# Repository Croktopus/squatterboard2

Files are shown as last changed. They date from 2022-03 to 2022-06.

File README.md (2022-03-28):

# squatterboard2

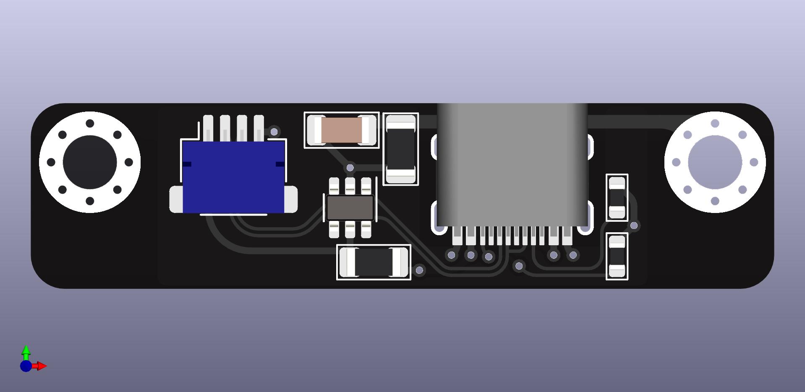
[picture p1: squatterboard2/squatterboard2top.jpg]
thumb


This is an update to the [squatterboard project](https://github.com/Croktopus/squatterboard), meant to resolve issues I have with the original. If you're not familiar with the original, the reason I made this was to make a daughterboard with a "squatter" profile than the standard set by the [Unified Daughterboard](https://github.com/ai03-2725/Unified-Daughterboard) (UDB), since I almost never have room in my cases for a daughterboard with those dimensions.

Electrically, it is compatible with the UDB's pinout, so it can work with any PCB compatible with the UDB. I honestly do not know how it compares for effectiveness because I don't have access to proper testing equipment, and I do know that the routing is not perfectly optimal (I made a couple slight compromises to fit everything a bit tighter and, I'll be honest, to keep the routing clean), but I'm confident that it is good enough (Cunningham's Law inc).

While you are welcome to use this DB as is without any modification, I am not proposing it as an alternative standard, and I encourage you to modify it to fit your needs, because that's why it was made in the first place; as a modification of the UDB concept to fit my needs.

Major changes from the original squatterboard:

* Built from scratch in KiCad 6
* Simplified the schematic & componentry
* Made it a bit squatter (loses physical compatibility, but I kinda just don't care about that, as I said above you can modify it to fit your needs, including moving some stuff around to restore physical compat)
* Reorganized libraries, added license, basically just trying to make the whole package a bit more portable so you don't get hit with errors when you download it and try to play around with it - let me know if I failed on that front, this was one of the big reasons I had for redoing this whole thing

Major changes relative to the UDB

* Size and shape (obviously)
* Optimized for JLC assembly with basic parts wherever possible (production files are included, though they haven't been tested as of writing)
* 2 M3 screws instead of 4 M2

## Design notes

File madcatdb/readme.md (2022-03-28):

this directory is for a modification I've made to the squatterboard for a specific keyboard I'm working on where it will be mounted upside down, so the mounting hole not used for shielding is flipped. This change is almost entirely aesthetic, feel free to ignore this directory entirely.

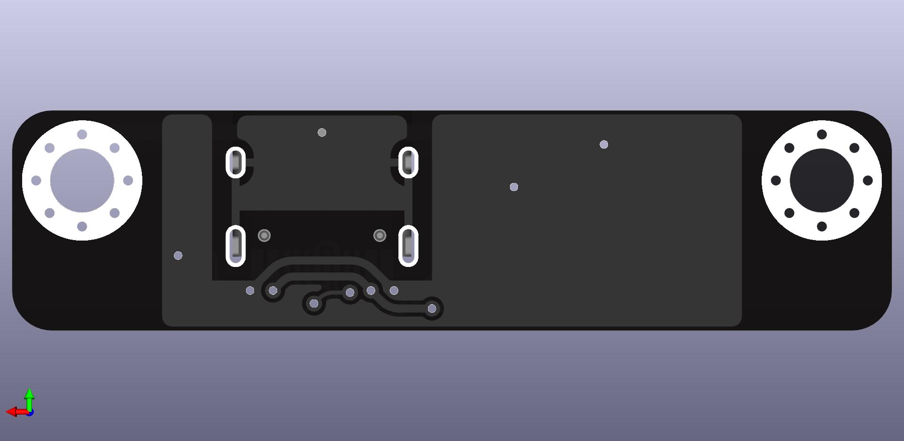
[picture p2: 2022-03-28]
madcatdb/madcatdbbot.jpg

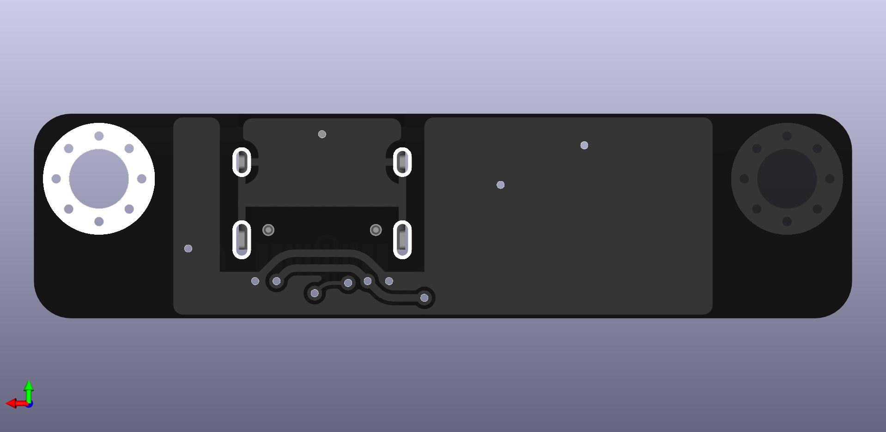
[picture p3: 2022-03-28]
squatterboard2/squatterboard2bot.jpg

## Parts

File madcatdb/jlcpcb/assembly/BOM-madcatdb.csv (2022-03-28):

Comment | Designator | Footprint | LCSC
Conn_01x04 | J2 | JST_SH_SM04B-SRSS-TB-Handsoldering | C160404
USB_C_Receptacle_USB2.0 | J1 | USB_C_Receptacle_HRO_TYPE-C-31-M-12 | C167321
1M | R3 | R_1206_3216Metric | C17927
5.1k | R1,R2 | R_0603_1608Metric | C23186
100n | C1 | C_1206_3216Metric | C24497
500mA | F1 | Fuse_1206_3216Metric | C70076
SRV05-4 | U1 | SOT-23-6 | C85364
M3 | H1 | M3_Via_Hole_NC
M3_Pad | H2 | M3_Via_Hole
JLCJLCJLCJLC | H3 | JLCJLCJLCJLC

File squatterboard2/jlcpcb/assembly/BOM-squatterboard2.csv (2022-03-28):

Comment | Designator | Footprint | LCSC
1M | R3 | R_1206_3216Metric
USB_C_Receptacle_USB2.0 | J1 | USB_C_Receptacle_HRO_TYPE-C-31-M-12
5.1k | R1 | R_0603_1608Metric
500mA | F1 | Fuse_1206_3216Metric
SRV05-4 | U1 | SOT-23-6
Conn_01x04 | J2 | JST_SH_SM04B-SRSS-TB-Handsoldering
100n | C1 | C_1206_3216Metric
JLCJLCJLCJLC | H3 | JLCJLCJLCJLC
M3_Pad | H2 | M3_Via_Hole
5.1k | R2 | R_0603_1608Metric
M3 | H1 | M3_Via_Hole_NC

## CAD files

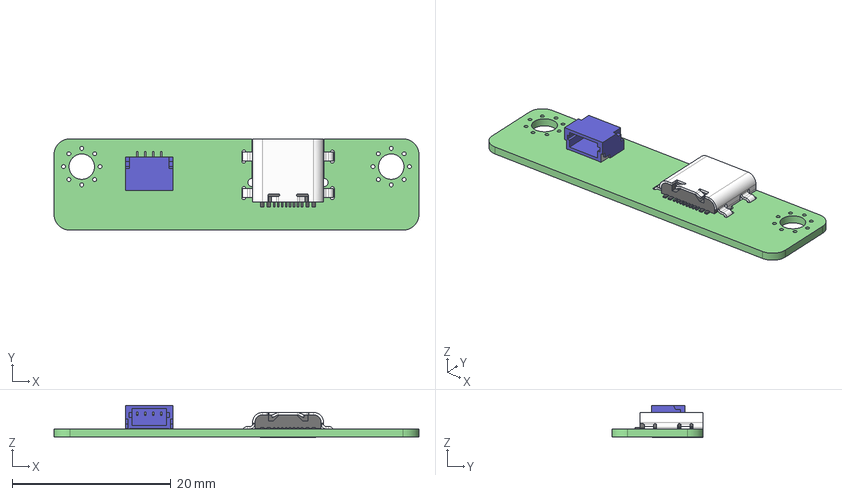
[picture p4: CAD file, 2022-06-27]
madcatdb/madcatdb.step
46.0 x 11.5 x 4.05 mm
madcatdb PCB

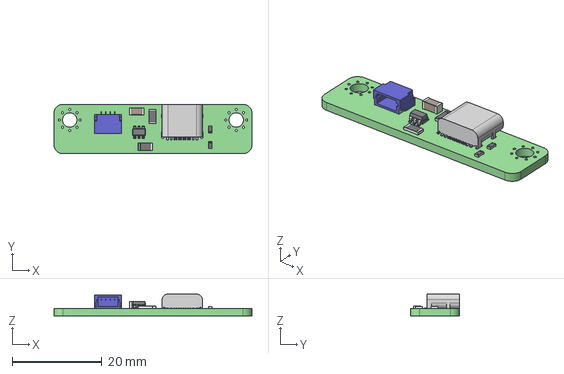
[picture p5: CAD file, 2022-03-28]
squatterboard2/squatterboard2.step
44.0 x 11.0 x 4.86 mm
_autosave-squatterboard2 PCB

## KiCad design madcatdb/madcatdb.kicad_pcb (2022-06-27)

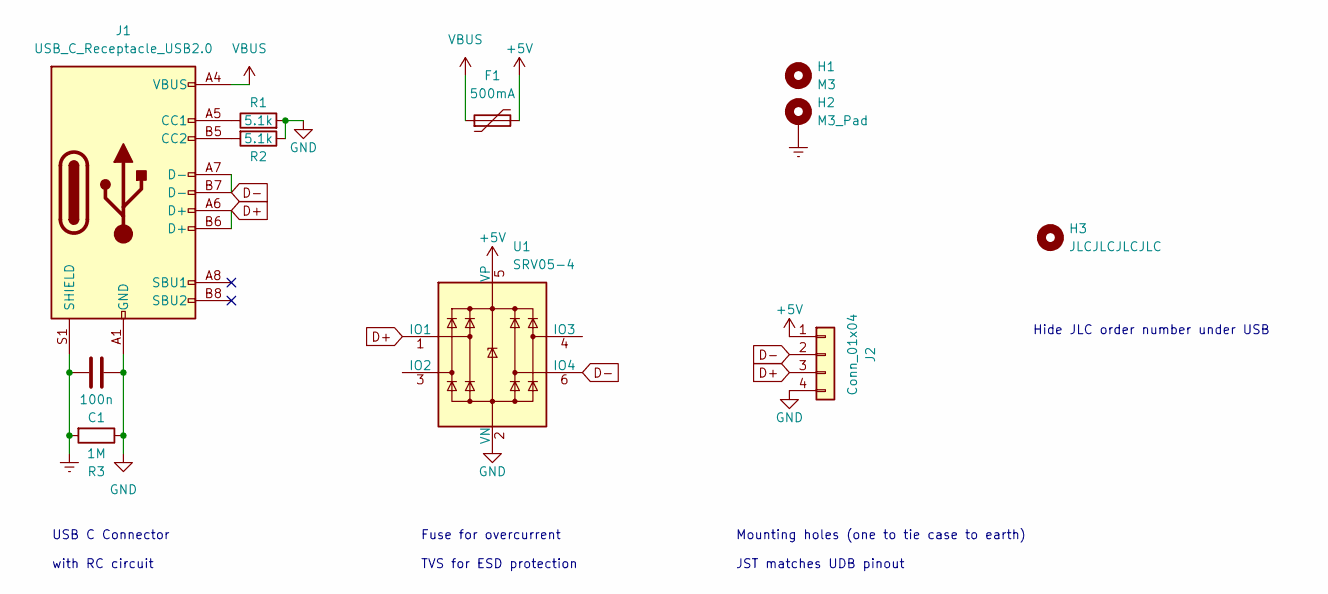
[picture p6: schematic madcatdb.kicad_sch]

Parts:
C1: 100n; C_1206_3216Metric
F1: 500mA; Fuse_1206_3216Metric
H1: M3; M3_Via_Hole_NC
H2: M3_Pad; M3_Via_Hole
H3: JLCJLCJLCJLC
J1: USB_C_Receptacle_USB2.0; HRO-TYPE-C-31-M-14
J2: Conn_01x04; JST_SH_SM04B-SRSS-TB-Handsoldering
R1, R2: 5.1k; R_0603_1608Metric
R3: 1M; R_1206_3216Metric
U1: SRV05-4; SOT-23-6

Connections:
+5V: F1.2, J2.1, U1.5 (VP)
D+: J1.A6 (D+), J1.B6 (D+), J2.3, U1.1 (IO1)
D-: J1.A7 (D-), J1.B7 (D-), J2.2, U1.6 (IO4)
Earth: C1.2, H2.1, J1.S1 (SHIELD), R3.2
GND: C1.1, J1.A1 (GND), J1.A12 (GND), J1.B1 (GND), J1.B12 (GND), J2.4, R1.2, R2.1, R3.1, U1.2 (VN)
unnamed: J1.A5 (CC1), R1.1
unnamed: J1.B5 (CC2), R2.2
VBUS: F1.1, J1.A4 (VBUS), J1.A9 (VBUS), J1.B4 (VBUS), J1.B9 (VBUS)

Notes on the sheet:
USB C Connector with RC circuit
Fuse for overcurrent TVS for ESD protection
Hide JLC order number under USB
Mounting holes (one to tie case to earth) JST matches UDB pinout

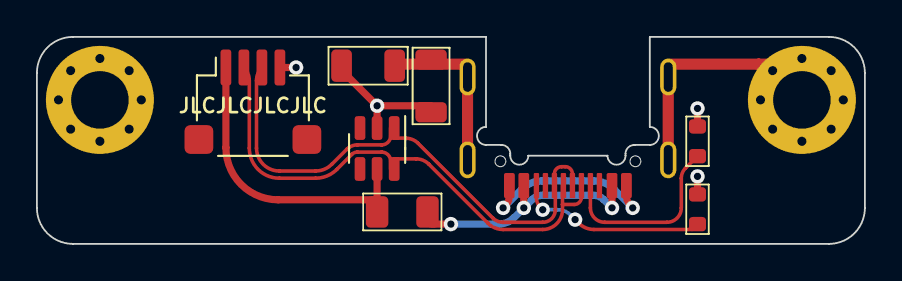
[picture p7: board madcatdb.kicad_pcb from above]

Board: 2 copper layers, 46.0 x 11.5 mm, 11 parts (1 on the bottom side), 8 nets.

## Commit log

2022-03-25 started kicad project
    [madcatdb.kicad_pcb, madcatdb.kicad_sch]
2022-03-26 done (lol)
    [madcatdb.kicad_pcb, madcatdb.kicad_sch]
2022-03-26 prod files
    [BOM-madcatdb.csv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]
2022-03-28 generated prod files
    [BOM-madcatdb.csv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]
2022-03-28 Update kicad-custom-libs
2022-03-28 added generic squatterboard2 version
    [BOM-madcatdb.csv, BOM-squatterboard2.csv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]
2022-04-07 proto ordered
    [madcatdb-CuBottom.gbr, madcatdb-CuTop.gbr, madcatdb-EdgeCuts.gbr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]
2022-06-27 updated madcat to mid mount
    [madcatdb.kicad_pcb, madcatdb.kicad_sch, madcatdb.step]
